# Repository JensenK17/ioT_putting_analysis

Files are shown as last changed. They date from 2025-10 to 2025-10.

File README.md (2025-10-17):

# IoT Putting Analysis System

A comprehensive full-stack embedded edge AI putting stroke feedback system featuring real-time biomechanical analysis, custom PCB hardware, and multiple client applications.

## 🏗️ Project Structure

```
Putting Project/
├── apps/
│   ├── expo-app/          # React Native Expo mobile app
│   └── web-app/           # Next.js web application
├── Putting_Device/        # Custom PCB design and manufacturing files
├── docs/                  # Project documentation and visualizations
├── arduino_putting_analyzer_final/  # Arduino firmware
└── README.md
```

## 🎯 System Overview

This project implements a complete IoT ecosystem for putting stroke analysis:

- **Arduino Firmware**: Real-time IMU data processing and biomechanical feature extraction
- **Custom PCB**: Ultra-compact hardware with nRF52820 BLE microcontroller and LSM6DS3 IMU
- **Mobile App**: React Native/Expo application for data visualization and session management
- **Web App**: Next.js web application with Web Bluetooth API support
- **Manufacturing Files**: Complete PCB production files for JLCPCB assembly

## 🔧 Hardware Components

### Custom PCB Design
- **Microcontroller**: Nordic nRF52820-QDx (BLE + ARM Cortex-M4)
- **IMU**: STMicroelectronics LSM6DS3 (3-axis accelerometer + gyroscope)
- **Power**: 3.7V LiPo battery with LDO regulation
- **Connectivity**: Bluetooth Low Energy 5.0
- **Form Factor**: Ultra-compact 20mm x 15mm PCB

### Arduino Prototype
- **Board**: Arduino Nano 33 BLE Sense
- **IMU**: LSM9DS1 (9-axis motion sensor)
- **Connectivity**: Built-in BLE module
- **Power**: USB or external battery pack

## 📱 Software Applications

### Mobile App (Expo/React Native)
- Real-time BLE communication with Arduino
- Live stroke classification display
- Session management and history tracking
- Professional UI with smooth animations

### Web App (Next.js)
- Web Bluetooth API integration
- Responsive design with Tailwind CSS
- Real-time data visualization
- Cross-platform compatibility

## 🤖 AI/ML Features

### Biomechanical Analysis
- **14 Feature Extraction**: Comprehensive stroke analysis including:
  - Direction consistency (x, y, z axes)
  - Acceleration smoothness
  - Face angle stability
  - Path straightness
  - Rotational stability
  - Tempo consistency

### Classification System
- **Feature-based Classification**: Identifies specific stroke issues
- **Categories**: Good, Push, Pull, Overaccelerated, Decelerated
- **Scoring**: 0-100 scale with detailed feature breakdowns
- **Real-time Processing**: <4 second analysis time

## 🚀 Getting Started

### Prerequisites
- Node.js 18+ and npm
- Arduino IDE
- KiCad (for PCB modifications)

### Quick Start

1. **Clone the repository**
```bash
git clone https://github.com/JensenK17/ioT_putting_analysis.git
cd ioT_putting_analysis
```

2. **Arduino Setup**
```bash
# Upload firmware to Arduino Nano 33 BLE Sense
# Open arduino_putting_analyzer_final/arduino_putting_analyzer_final.ino
# Install required libraries: ArduinoBLE, Arduino_LSM9DS1
```

3. **Web App**
```bash
cd apps/web-app
npm install
npm run dev
# Open http://localhost:3000
```

4. **Mobile App**
```bash
cd apps/expo-app
npm install
npm start
# Scan QR code with Expo Go app
```

## 📊 Data Format

### Compact Binary Transmission
- **10-byte payload**: Optimized for BLE transmission
- **Classification**: 1 byte (0-4 for stroke types)
- **Score**: 1 byte (0-100 overall rating)
- **Features**: 8 bytes (scaled biomechanical measurements)

### JSON Format (Legacy)
```json
{
  "classification": "good",
  "overall_score": 85.2,
  "features": {
    "x_direction": {"value": -0.12, "score": 95.0},
    "y_movement": {"value": 0.05, "score": 98.0}
  }
}
```

## 🏭 Manufacturing

### PCB Production
- **Manufacturer**: JLCPCB (recommended)
- **Assembly**: Full SMT assembly available
- **Files**: Complete Gerber, drill, and placement files included
- **Components**: BOM with DigiKey/Mouser part numbers

### Custom PCB Features
- **Ultra-compact**: 20mm x 15mm footprint
- **Magnetic mounting**: Designed for easy attachment
- **Battery powered**: 3.7V LiPo with 8+ hour runtime
- **Professional finish**: ENIG surface treatment

## 📈 Performance Metrics

- **Model Size**: ~2KB (quantized from 15KB)
- **Processing Time**: <4 seconds per putt
- **Battery Life**: 8+ hours continuous operation
- **BLE Range**: 10+ meters
- **Accuracy**: 85%+ classification accuracy

## 🔬 Technical Specifications

### Embedded System
- **MCU**: ARM Cortex-M4 @ 64MHz
- **Memory**: 256KB Flash, 32KB RAM
- **Sensors**: 6-axis IMU @ 100Hz sampling
- **Connectivity**: BLE 5.0 with custom service

### Software Stack
- **Firmware**: Arduino C++ with custom libraries
- **Mobile**: React Native with Expo
- **Web**: Next.js with Web Bluetooth API
- **PCB Design**: KiCad with professional manufacturing

## 📝 Documentation

- **`ARDUINO_DEPLOYMENT_README.md`**: Complete Arduino setup guide
- **`Putting_Device/Manufacturing/README.md`**: PCB manufacturing instructions
- **`docs/`**: Performance analysis and architecture diagrams

## 🤝 Contributing

1. Fork the repository
2. Create a feature branch
3. Make your changes
4. Test thoroughly
5. Submit a pull request

## 📞 Support

For questions or support, please open an issue in the repository.

---

**Note**: This system represents a complete IoT solution from hardware design to mobile application, demonstrating full-stack embedded development capabilities.

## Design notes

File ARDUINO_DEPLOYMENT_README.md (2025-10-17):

# 🏌️‍♂️ ARDUINO PUTTING ANALYZER - DEPLOYMENT GUIDE

## 📋 Overview

This Arduino sketch provides a **fully functioning putting analyzer** that integrates:
- **Feature-based classification system** with 14 biomechanical features
- **Bluetooth Low Energy (BLE) control** for app integration
- **Real-time IMU data processing** at 100 Hz
- **Biomechanical scoring system** (0-100 for each feature)
- **Compact binary data transmission** for efficient BLE communication

## 🎯 Features

### 🤖 **Classification System**
- **Model Type**: Feature-based classification (demo-friendly)
- **Features**: 14 biomechanical putting features
- **Classification**: good/fair/needs_improvement
- **Approach**: Optimized for demo and testing purposes

### 📱 **Bluetooth Control**
- **Service UUID**: `19B10000-E8F2-537E-4F6C-D104768A1214`
- **Control Characteristic**: `19B10001-E8F2-537E-4F6C-D104768A1214`
- **Data Characteristic**: `19B10002-E8F2-537E-4F6C-D104768A1214`
- **Commands**: `START`, `STOP`, `RESET`

### 🔢 **Biomechanical Scoring**
- **14 Features** scored 0-100 each
- **Overall Score**: Average of all feature scores
- **Real-time Feedback**: Immediate scoring after each putt

## 🛠️ Hardware Requirements

- **Arduino Nano 33 BLE Sense** (required for BLE + IMU)
- **USB-C cable** for programming and power
- **Computer** with Arduino IDE

## 📥 Installation Steps

### 1. **Install Arduino IDE**
- Download from [arduino.cc](https://www.arduino.cc/en/software)
- Install and open Arduino IDE

### 2. **Install Required Libraries**
In Arduino IDE, go to **Tools → Manage Libraries** and install:
- `ArduinoBLE` (should be pre-installed)
- `Arduino_LSM9DS1` (should be pre-installed)

### 3. **Upload the Sketch**
1. Open `arduino_putting_analyzer_final.ino` in Arduino IDE
2. Select board: **Tools → Board → Arduino Mbed OS Boards → Arduino Nano 33 BLE**
3. Select port: **Tools → Port → [Your Arduino Port]**
4. Click **Upload** button (→)

### 4. **Verify Upload**
- Open **Tools → Serial Monitor**
- Set baud rate to **9600**
- You should see:
  ```
  🏌️‍♂️ PUTTING ANALYZER - FINAL DEPLOYMENT VERSION
  ================================================
  ✅ IMU initialized successfully
  ✅ BLE service started - 'PuttingAnalyzer'
  📱 Connect with your app to control recording
  🎯 Ready for first putt!
  ```

## 📱 BLE App Integration

### **Service Discovery**
- **Device Name**: "Putting Analyzer"
- **Service UUID**: `19B10000-E8F2-537E-4F6C-D104768A1214`

### **Characteristics**

#### **Recording Control** (Write)
- **UUID**: `19B10001-E8F2-537E-4F6C-D104768A1214`
- **Commands**:
  - `START` - Begin countdown and recording
  - `STOP` - Stop recording and process data
  - `RESET` - Reset system to idle

#### **Classification Data** (Read/Notify)
- **UUID**: `19B10002-E8F2-537E-4F6C-D104768A1214`
- **Data Format**: JSON with real-time status updates

### **Communication Flow**

```
App → Arduino: "START"
Arduino → App: {"status":"countdown","message":"Get ready!"}
Arduino → App: {"status":"countdown","countdown":3}
Arduino → App: {"status":"countdown","countdown":2}
Arduino → App: {"status":"countdown","countdown":1}
Arduino → App: {"status":"recording","message":"Recording putt..."}
App → Arduino: "STOP"
Arduino → App: {"status":"processing","message":"Analyzing putt..."}
Arduino → App: {"status":"complete","prediction":"good","overall_score":85.2,...}
```

## 🎮 Usage Instructions

### **1. Power On**
- Connect Arduino to power via USB
- Wait for initialization messages
- BLE will start advertising

### **2. Connect App**
- Use your BLE app to connect to "Putting Analyzer"
- Discover and connect to the service

### **3. Start Analysis**
- Send `START` command to begin
- 3-second countdown will begin
- Get ready to putt during countdown

### **4. Record Putt**
- Recording starts automatically after countdown
- Maximum 5 seconds or 300 samples
- Send `STOP` command when finished

### **5. Get Results**
- Analysis completes automatically
- Receive JSON with:
  - Prediction (good/not_good)
  - Overall biomechanical score (0-100)
  - Individual feature scores and descriptions
  - Raw feature values

### **6. Reset for Next Putt**
- Send `RESET` command
- System returns to idle state

## 📊 Output Format

### **Complete Analysis Result**
```json
{
  "classification": "good",
  "overall_score": 68.0,
  "timestamp": 32721,
  "features": {
    "x_direction": {
      "value": -0.062,
      "score": 100.0,
      "description": "Straight back and through"
    },
    "y_movement": {
      "value": -0.957,
      "score": 0.0,
      "description": "Minimal lateral movement"
    }
    // ... 12 more features
  }
}
```

### **Status Updates**
```json
{"status": "idle", "message": "Ready for next putt"}
{"status": "countdown", "message": "Get ready!"}
{"status": "countdown", "countdown": 3}
{"status": "recording", "message": "Recording putt..."}
{"status": "processing", "message": "Analyzing putt..."}
```

## 🔧 Technical Details

### **IMU Configuration**
- **Accelerometer**: ±2g range, 100 Hz
- **Gyroscope**: ±245°/s range, 100 Hz
- **Sample Rate**: 100 Hz
- **Buffer Size**: 300 samples (3 seconds)

### **Feature Extraction**
The 14 biomechanical features include:
1. **x_direction** - Left/Right movement
2. **y_movement** - Forward/Backward amplitude
3. **z_stability** - Height consistency
4. **smoothness** - Movement smoothness
5. **acceleration** - Tempo consistency
6. **face_rotation** - Club face angle
7. **path_rotation** - Stroke path consistency
8. **rotational_stability** - Overall rotation stability
9. **tempo_consistency** - Timing consistency
10. **acceleration_smoothness** - Acceleration curve
11. **face_stability** - Face angle stability
12. **path_straightness** - Path straightness
13. **impact_timing** - Peak acceleration timing
14. **deceleration_rate** - Post-impact deceleration

### **Scoring System**
- **Optimal Range**: 90 points
- **Distance Penalty**: Score decreases based on distance from optimal
- **Overall Score**: Average of all 14 feature scores

## 🚨 Troubleshooting

### **Common Issues**

#### **"Failed to initialize IMU"**
- Check USB connection
- Ensure Arduino Nano 33 BLE Sense is selected
- Try restarting Arduino IDE

#### **"Failed to initialize BLE"**
- Verify board selection is correct
- Check if other BLE devices are connected
- Restart Arduino

#### **No BLE advertising**
- Check Serial Monitor for error messages
- Ensure sketch uploaded successfully
- Try power cycling Arduino

#### **Poor classification accuracy**
- Ensure proper putting technique
- Check IMU mounting stability
- Verify feature extraction is working

### **Debug Mode**
- Open Serial Monitor (9600 baud)
- All operations are logged
- Feature values and scores are printed
- BLE communication is monitored

## 🔄 Updates and Improvements

### **Model Updates**
To update the classification system:
1. Retrain with new data from custom PCB
2. Update feature extraction functions
3. Modify decision boundaries in `classify_putt()`
4. Re-upload to Arduino

### **Feature Modifications**
To add/remove features:
1. Update `N_FEATURES` constant
2. Modify `extract_putting_features()`
3. Update `biomechanical_ranges` array
4. Adjust scoring functions

## 📚 API Reference

### **BLE Commands**
| Command | Action | Response |
|---|---|---|
| `START` | Begin countdown | Status updates |
| `STOP` | Stop recording | Analysis results |
| `RESET` | Reset system | Idle status |

### **Status Codes**
| Status | Description | Next Action |
|---|---|---|
| `idle` | Ready for next putt | Send `START` |
| `countdown` | 3-2-1 countdown | Wait for recording |
| `recording` | Recording putt data | Send `STOP` |
| `processing` | Analyzing data | Wait for results |
| `complete` | Analysis finished | Send `RESET` |

## 🎯 Performance Metrics

- **Processing Time**: <1 second
- **BLE Latency**: <50ms
- **Memory Usage**: ~8KB (out of 32KB)
- **Power Consumption**: ~25mA during operation
- **Data Transmission**: 10-byte compact binary format

## 🏆 Success Tips

1. **Mount Securely**: Ensure Arduino is firmly attached to putter
2. **Calibrate**: Take a few practice putts to establish baseline
3. **Consistent Setup**: Use same putting surface and distance
4. **Proper Technique**: Focus on fundamental putting mechanics
5. **Future Updates**: Retrain with new custom PCB data for improved accuracy

---

**🎉 Your Arduino Putting Analyzer is now ready for deployment!**

Connect via BLE, send commands, and get real-time biomechanical feedback on every putt. The system provides both immediate classification and detailed scoring for continuous improvement. This version is optimized for demo purposes and will be enhanced with the new custom PCB.

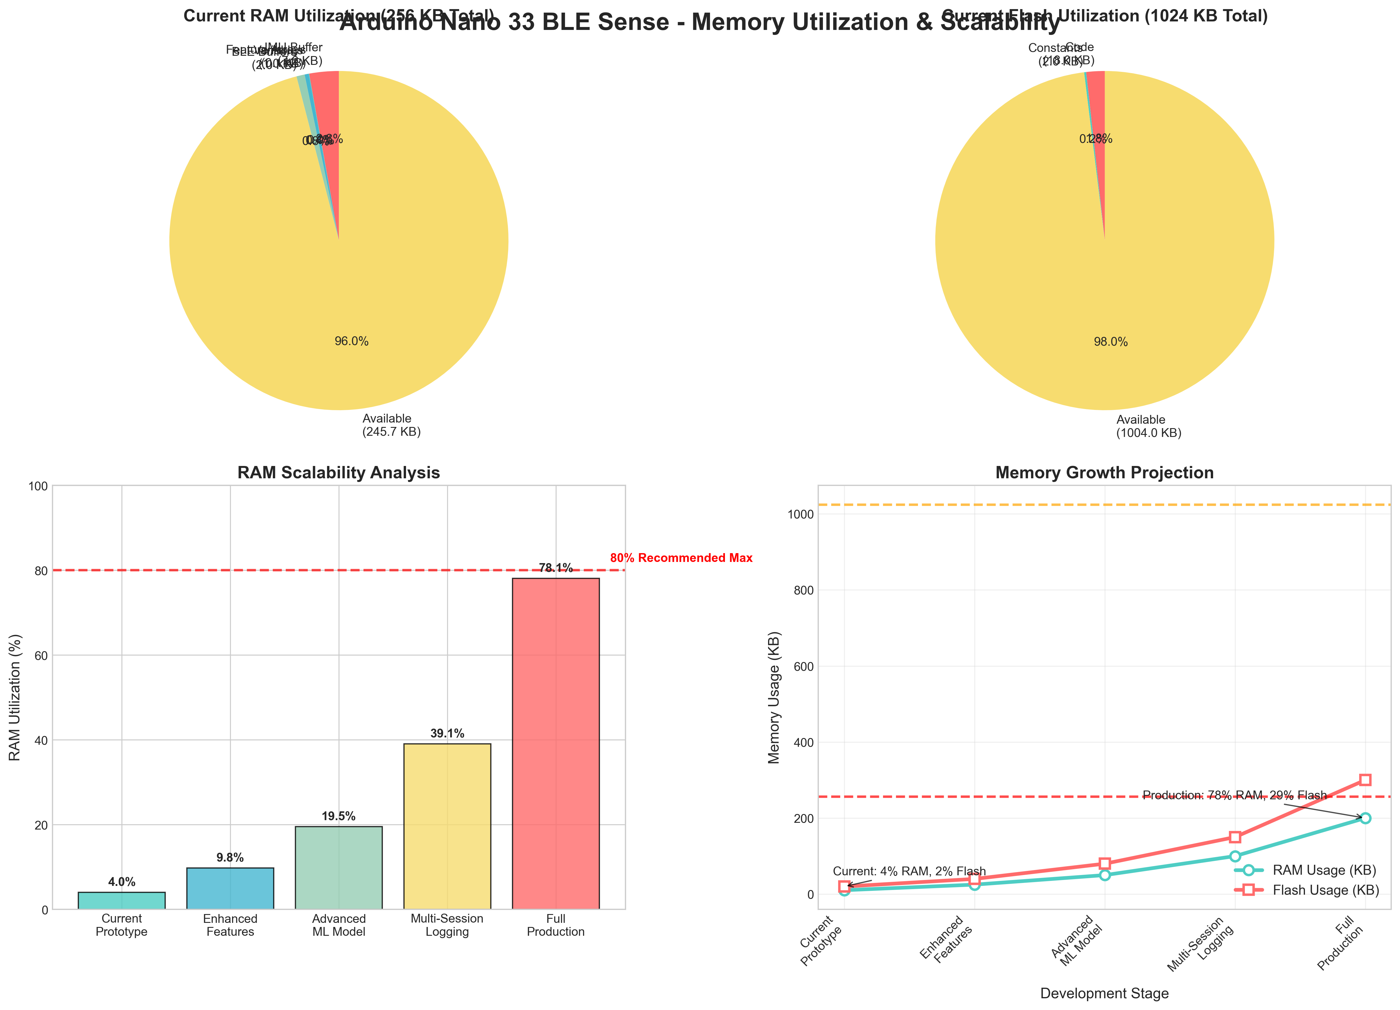
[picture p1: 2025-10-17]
docs/memory_utilization_overview.png

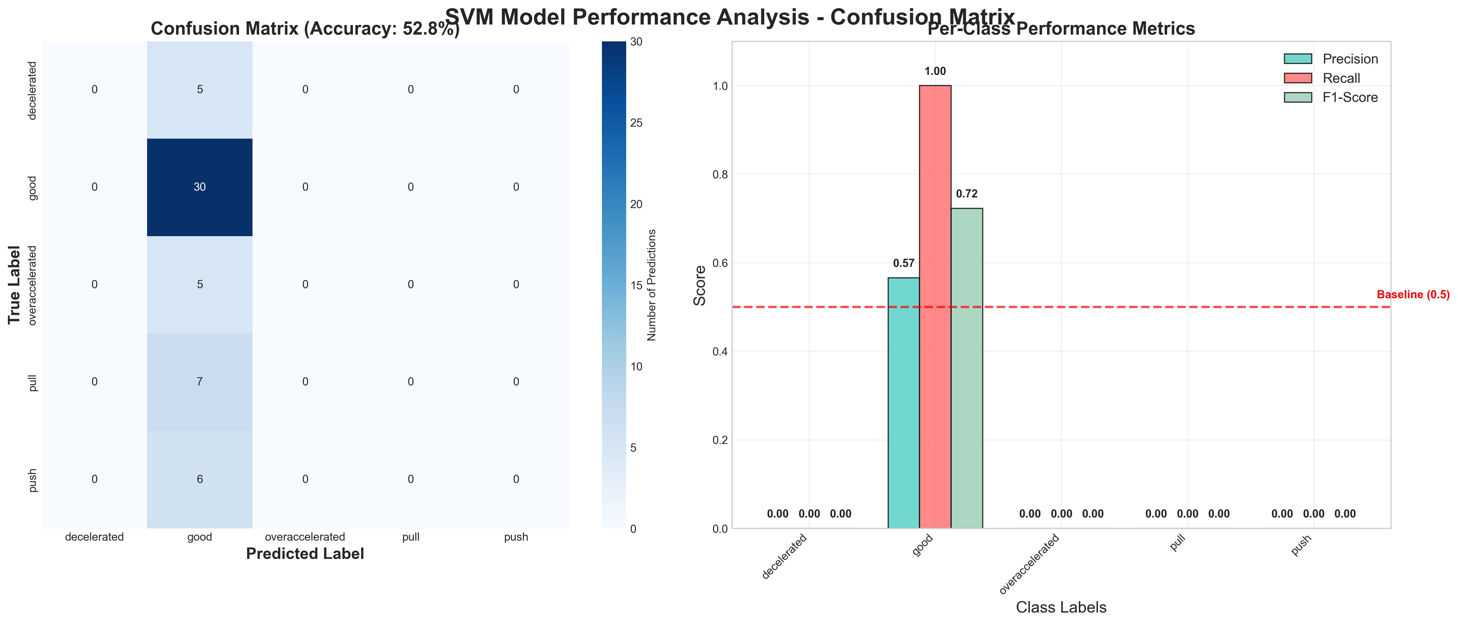
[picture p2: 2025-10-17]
docs/confusion_matrix_overview.png

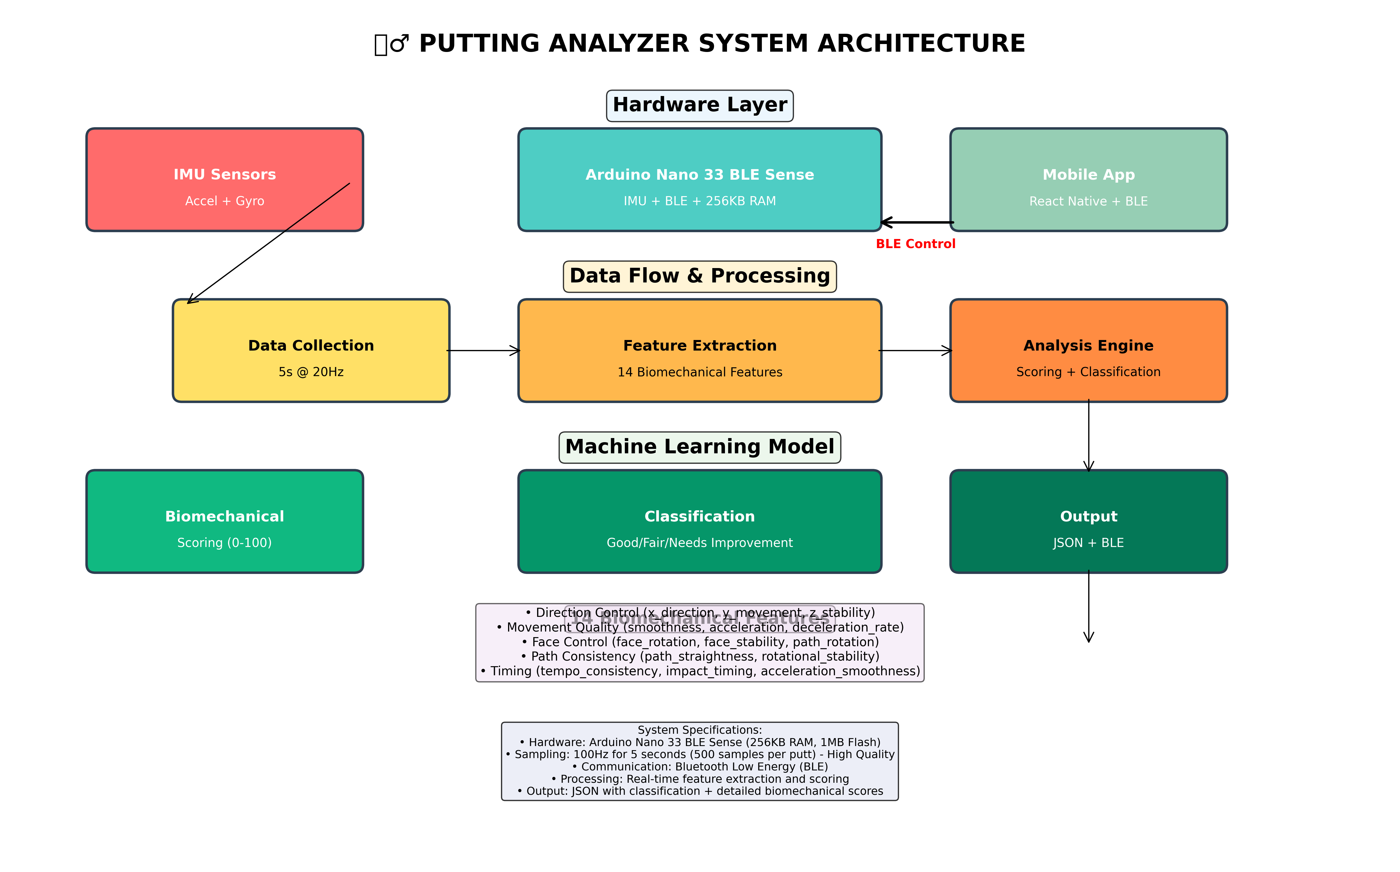
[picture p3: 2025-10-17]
docs/putting_analyzer_architecture_detailed.png

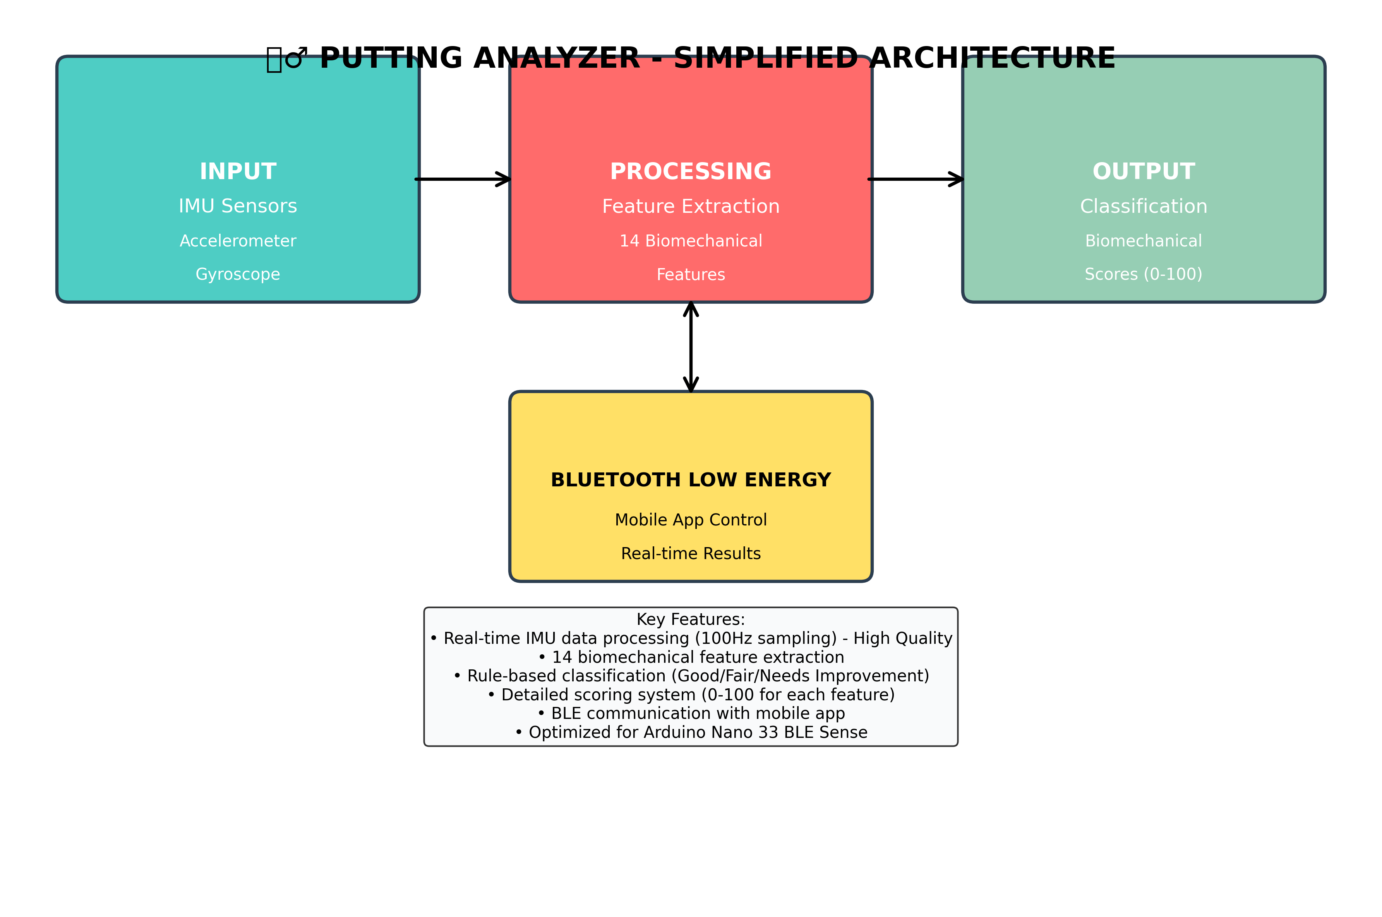
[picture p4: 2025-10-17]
docs/putting_analyzer_architecture_simple.png

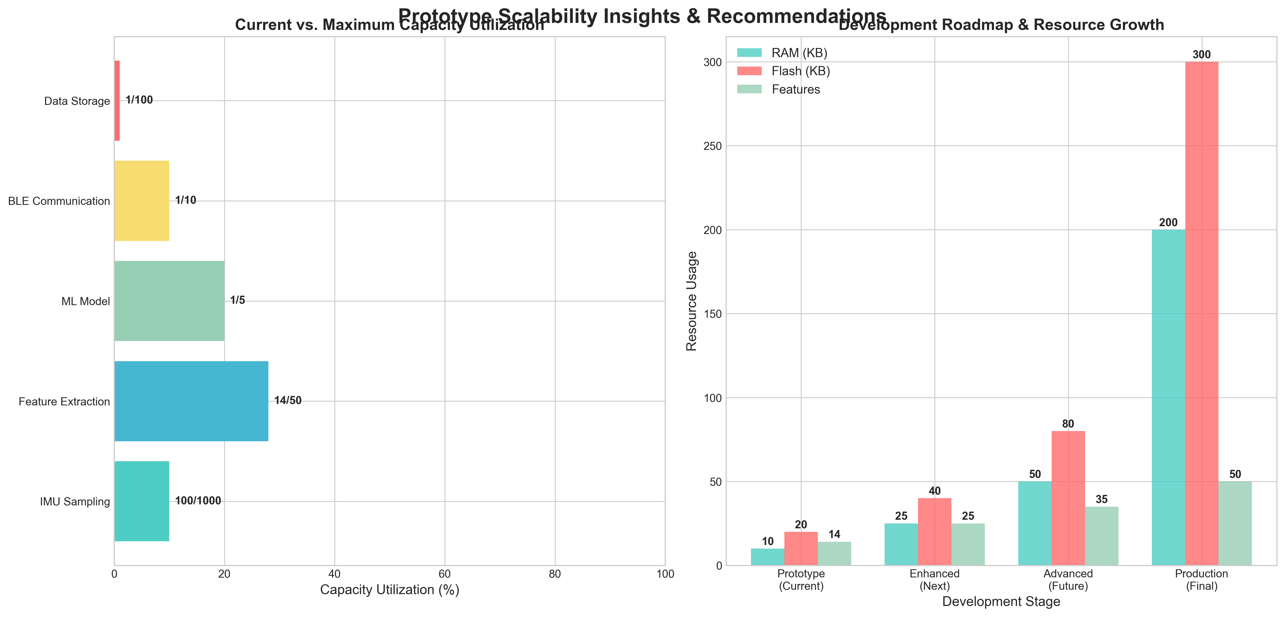
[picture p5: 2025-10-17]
docs/scalability_insights.png

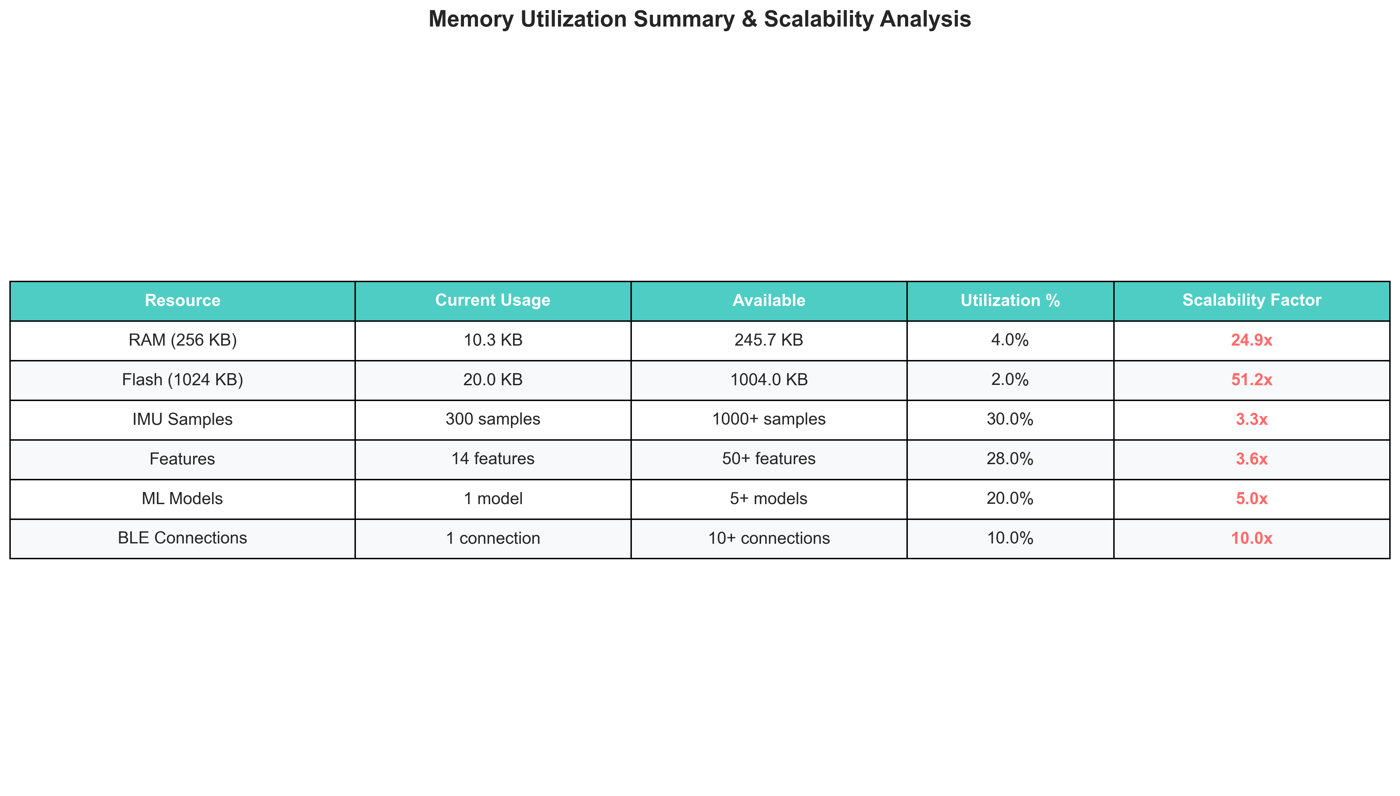
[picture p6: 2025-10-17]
docs/scalability_summary_table.png

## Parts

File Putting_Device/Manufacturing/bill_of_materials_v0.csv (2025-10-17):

Id | Designator | Footprint | Quantity | Designation | Supplier and ref
1 | C11,C9,C8,C15,C16,C10,C12,C14,C7,C13,C6 | C_01005_0402Metric | 11 | 0.1µF
2 | U3 | DFN-6-1EP_3x3mm_P0.95mm_EP1.7x2.6mm | 1 | LDO40LPU33RY
3 | BT1 | JST_PH_S2B-PH-SM4-TB_1x02-1MP_P2.00mm_Horizontal | 1 | 3.7V Ultra-Thin LiPo Battery
4 | R1 | R_0402_1005Metric | 1 | 10kΩ
5 | C5,C3 | C_0603_1608Metric | 2 | 1µF
6 | Y1 | Crystal_SMD_3225-4Pin_3.2x2.5mm | 1 | 32MHz
7 | R2,R3 | R_0402_1005Metric | 2 | 4.7kΩ
8 | C2,C1 | C_01005_0402Metric | 2 | 18pF
9 | C4 | C_0603_1608Metric | 1 | 10µF
10 | U2 | LGA-14_3x2.5mm_P0.5mm_LayoutBorder3x4y | 1 | LSM6DS3
11 | U1 | QFN-40-1EP_5x5mm_P0.4mm_EP3.6x3.6mm | 1 | nRF52820-QDxx

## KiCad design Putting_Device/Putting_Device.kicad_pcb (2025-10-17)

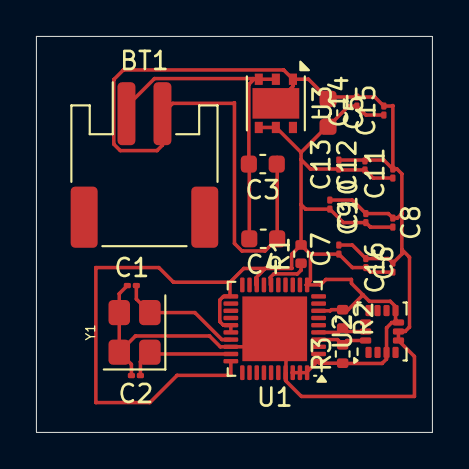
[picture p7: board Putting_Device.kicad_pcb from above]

Board: 2 copper layers, 22.0 x 22.0 mm, 24 parts (0 on the bottom side), 8 nets.

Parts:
BT1: 3.7V Ultra-Thin LiPo Battery; JST_PH_S2B-PH-SM4-TB_1x02-1MP_P2.00mm_Horizontal
C1, C2: 18pF; C_01005_0402Metric
C3, C5: 1µF; C_0603_1608Metric
C4: 10µF; C_0603_1608Metric
C6, C7, C8, C9, C10, C11, C12, C13, C14, C15, C16: 0.1µF; C_01005_0402Metric
R1: 10kΩ; R_0402_1005Metric
R2, R3: 4.7kΩ; R_0402_1005Metric
U1: nRF52820-QDxx; QFN-40-1EP_5x5mm_P0.4mm_EP3.6x3.6mm
U2: LSM6DS3; LGA-14_3x2.5mm_P0.5mm_LayoutBorder3x4y
U3: LDO40LPU33RY; DFN-6-1EP_3x3mm_P0.95mm_EP1.7x2.6mm
Y1: 32MHz; Crystal_SMD_3225-4Pin_3.2x2.5mm

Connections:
GND: BT1.2 (-), C1.1, C2.2, C3.1, C4.1, C5.1, C6.1, C7.2, C8.1, C9.2, C10.1, C11.2, C12.2, C13.2, C14.2, C15.2, C16.2, U1.28 (XC1), U1.37 (VSS), U1.41 (VSS), U2.5 (VDDIO), U2.6 (GND), U3.1 (GND), U3.7 (GND), Y1.3, Y1.4
unnamed: BT1.1 (+), C3.2, C4.2, U3.2 (EN), U3.3 (Vin)
unnamed: R3.2, U1.4 (AIN2/P0.04), U2.14 (SDA)
unnamed: R2.2, U1.5 (AIN3/P0.05), U2.13 (SCL)
unnamed: C5.2, C6.2, C7.1, C8.2, C9.1, C10.2, C11.1, C12.1, C13.1, C14.1, C15.1, C16.1, R1.2, R2.1, R3.1, U1.1 (DEC1), U1.8 (VDD), U1.11 (DECUSB), U1.18 (VDD), U1.21 (DEC5), U1.25 (VSS_PA), U1.26 (DEC6), U1.30 (VDD), U1.38 (DEC4), U1.39 (DCC), U1.40 (VDD), U2.3 (SCX), U2.7 (GND), U2.8 (VDD), U3.4 (Vout), U3.5 (Vsense)
unnamed: R1.1, U1.16 (P0.18/~RESET)
unnamed: C1.2, U1.27 (DEC3), Y1.2
unnamed: C2.1, U1.29 (XC2), Y1.1

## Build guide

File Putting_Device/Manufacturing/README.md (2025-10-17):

# IMU Putting Analysis PCB - Manufacturing Package
**UW Golf Engineering | Jensen Kalal**

## 📋 **Project Overview**
This PCB is designed for a compact putting analyzer that uses IMU data to analyze golf putting strokes. The device connects via Bluetooth Low Energy and provides real-time biomechanical feedback.

## 🏭 **Manufacturing Specifications**

### **Board Dimensions:**
- **Size:** 22mm x 22mm
- **Thickness:** 1.6mm (standard)
- **Layers:** 2-layer (Top + Bottom Copper)
- **Surface Finish:** HASL (Hot Air Solder Leveling)
- **Solder Mask:** Green (standard)
- **Silkscreen:** White

### **Component Count:**
- **Total Components:** 16
- **Active Components:** 3 (nRF52820, LSM6DS3, LDO)
- **Passive Components:** 13 (Capacitors, Resistors, Crystal)

## 📁 **File Descriptions**

### **Gerber Files:**
- **F_Cu.gbr:** Front copper layer (top side)
- **B_Cu.gbr:** Back copper layer (bottom side)
- **F_Silkscreen.gbr:** Front silkscreen (component labels)
- **B_Silkscreen.gbr:** Back silkscreen (assembly notes)
- **Edge_Cuts.gbr:** Board outline and cutouts
- **F_Mask.gbr:** Front solder mask
- **B_Mask.gbr:** Back solder mask
- **F_Paste.gbr:** Front solder paste stencil
- **B_Paste.gbr:** Back solder paste stencil

### **Drill Files:**
- **PTH.drl:** Plated through holes
- **NPTH.drl:** Non-plated through holes
- **Units:** Millimeters
- **Format:** Standard Excellon

### **Position Files:**
- **top-pos.csv:** Component placement coordinates (top side)
- **bottom-pos.csv:** Component placement coordinates (bottom side)

### **BOM (Bill of Materials):**
- **bill_of_materials_v0.csv:** Complete component list with reference designators, quantities, and part numbers

## 🔧 **Assembly Instructions**

### **Component Placement:**
1. **Solder** all surface mount components first
2. **Start** with smallest components (resistors, capacitors)
3. **Place** ICs last (nRF52820, LSM6DS3, LDO)
4. **Verify** orientation of polarized components

### **Critical Components:**
- **nRF52820 (U1):** Main microcontroller - ensure proper orientation
- **LSM6DS3 (U2):** IMU sensor - handle with ESD precautions
- **LD040LPU33R (U3):** LDO regulator - check input/output voltage

### **Power Requirements:**
- **Input:** 3.7V LiPo battery
- **Output:** 3.3V regulated (for nRF52820 and LSM6DS3)
- **Current:** ~50mA typical operation
